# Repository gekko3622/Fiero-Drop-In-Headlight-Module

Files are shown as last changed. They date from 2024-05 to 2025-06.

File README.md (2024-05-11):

# 1987-1988 Pontiac Fiero OEM Drop-In Headlight Motor Controller
**PCB Designed by Ryan Blanchard 4.2024**\
**Based On A Project by WalkerTexan**\
**FOR NON-COMMERCIAL USE ONLY.**



**Important:** Please pay attention to the Bill of Materials (BOM). Some components have been changed from my previous designs.\
**This PCB MUST be fabricated with 2 Oz Outer Copper Weight for power handling and safety.**

## Intro

This is a PCB implementation of WalkerTexan's "Fiero Headlight Controller" project.\
I started this project after getting frustrated with the cost and questionable reliability of used modules.\
While there are new reproductions of the original module available, I found the cost to be too high.

After publishing my original PCB implementation, I was challenged to make it fit inside the original GM module's housing. Here it is.

## Repository Contents

**1. Arduino Program**
- WalkerTexan's code for the Arduino Nano.\
This MUST be programmed onto the Pro Micro for the module to function.

**2. Gerber Files (For Production)**
- These are the files that must be provided to a fabricator to produce a PCB.\
  **VERY IMPORTANT:** This PCB MUST be produced with 2 Oz outer copper weight in order to meet power handling requirements.\
  The provided gerber files will produce an identical copy of the PCB installed in my own car, just minus my logo.

  The Zip file can be directly submitted to a fabricator and contains all of the other individual files in this folder.

**3. KiCad Project Files**
- These are my full design schematic and PCB layout files. Use them for learning PCB design or to create your own custom version of the module.

  This project requires KiCad v8 or higher.

## Requirements
This project requires that you already have a fried 87-88 headlight module. (You're considering this project for a reason, right?)\
A Firebird or Corvette module of similar design can also be used.

- You will need to desolder and re-use the original 4 and 5 pin headers from your original module.
- The original module case will also be reused, but requires a single modification.

## Important Building Tips

**1. Arduino Pro Micro**

Due to the low clearance of the GM module casing, the Pro Micro must be installed lower on its pins than standard.\
It is also installed in a DIP socket to further reduce the mounting height.

My recommendation is to install the DIP socket first, then push the Pro Micro's pins into it.\
While installed, push down the plastic spacer, moving side to side until it's as flush as possible with the socket.



You can really see the difference in this side-by-side:



Once you've adjusted the pins for each side, place the Pro Micro onto the pins and solder it while socketed.

**2. Fuses**

I designed the module to directly solder in standard automotive mini fuses.\
For my own board, I used low profile mini fuses in order to avoid having to trim the fuse legs.

Regular mini fuses will work fine, just trim the legs after soldering.
  - 15 amps should be fine assuming your motors are in good shape.



**3. 4/5 Pin Original Header Pins**

The header pins must be installed slightly pulled out from the board to compensate for the added height of the relays.\
I tried my best to capture an image to demonstrate the needed spacing, but it's hard get a clear shot when assembled.



I found it easiest to install the pins one side at a time, getting them lined up right when installed into the housing.\
The holes for the headers are a pretty tight fit, so you should be able to position them fairly easily without them falling out.\
Once I was satisfied with the fitment, I lightly soldered a pin or two per side while still in the casing just to make sure the alignment was right.

**4. Modifying the Module Case**

The sole casing modification needed is to remove most of the plastic spacers from the back panel.\
The plastic is pretty soft, so I was able to grab and twist with vice grips to remove most of the material.

**You do not need to fully remove the spacers, just enough so the back panel can be re-installed without flexing.**\
**The round corner pieces do not need to be removed.**

Here's a comparison of an intact panel and my hastily trimmed panel. If you have the time, sanding them would give a more precise fit.

image0(2)

## Modifications to Original Source
1. Recreated the schematic diagram in KiCad.
2. Designed a PCB based on the schematic.
3. Added fuses and changed the power-on circuit to draw its power from the second 12V source.
4. Substituted the relays for a smaller part with higher current rating.
5. Adapted for compatibility with the original headlight module.

## Credits
The electrical schematic and Arduino code this project is based on were created by WalkerTexan.\
See his original project here: https://www.hackster.io/walkertexan/fiero-headlight-controller-8eaa4c

KiCad Schematic and PCB Layout/Design by Ryan Blanchard.

## License
This project is published under the Creative Commons Attribution-NonCommercial-ShareAlike 4.0 International license.\
Use of this project for commercial purposes is prohibited.

For full details, see the license file.

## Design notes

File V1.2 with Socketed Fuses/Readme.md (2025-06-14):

V1.2 maintains the same BOM but adds socketed fuse holders.\
The specific holders I used are the micro fuse holders on this listing:\
https://www.aliexpress.us/item/2255800354773238.html

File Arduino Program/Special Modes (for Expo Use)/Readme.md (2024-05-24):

# Custom Arduino Program To Enable Special Toggles
**Legal Disclaimer: This program is FOR OFF-ROAD AND EXHIBITION USE ONLY. Winking and sleepy headlight mode are probably not legal on most public roads.**

*Personal disclaimer: I am not a programmer by trade nor am I a particularly good one. Use my modifications at your own risk.*

## How to Use
Program the file "Fiero Headlight Toggle Modes 1_0.ino" to your Arduino in place of the standard programming. It contains most of the same code as the original but with additions to enable fun headlight behaviors.

Modes are activated using the headlight switch. Upon turning the headlight switch off, you have 1 second to enter a command (detailed below).

If the headlight switch is left off for more than 1 second, the headlights will close and the module will turn off.

## Available Toggles
### Wink
You can wink either the left or right headlight by turning the headlight switch off, then back on within 1 second.\
The amount of time between turning the switch off and on determines which side will wink.

**Right headlight:** turn the headlight switch off and on within half a second.

**Left headlight:** turn the headlight switch off, wait half a second, then turn it back on.

### Sleepy Mode
Sleepy mode and normal mode are toggled back and forth using the same command.\
To switch between normal and sleepy mode, turn the headlight switch off and on twice. (off>on>off>on)

Each flip must be completed within one second of the last action.

Winking in sleepy mode works the same as normal.

## Troubleshooting
**Sleepy mode winks are not returning the lights to the correct height.**
  * You will need to adjust the motor run timing manually for your own car.
    * For the left light, adjust the value of 'count' on line 385.
    * For the right light, adjust the value of 'count' on line 489.
  * Setting 'count' to a higher value will reduce the motor run time, lifting the light lower.
  * Setting 'count' to a lower value will increase the motor run time, lifting the light higher.
  * 'count' has a maximum limit of 150. Setting it to 150 or higher will not run the motor at all.

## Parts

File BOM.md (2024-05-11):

# Bill of Materials

**Note:** The Quantity column indicates the number of each component that is required.\
Many electrical components are sold in bulk. Please pay attention to each product page so you don't massively overpurchase.

| Component | Quantity | Position | Link | Notes |
| --- | --- | --- | --- | --- |
| Arduino Pro Micro | 1 | A1 | https://www.amazon.com/dp/B01MTU9GOB/ | Program the board as "Arduino Leonardo" |
| 30A Current Sensor Module | 2 | U2, U3 | https://www.amazon.com/dp/B07SPRL8DL/ | Terminals and pins must be desoldered |
| JQC-T78-DC05V-C | 4 | K1, K2, K3, K4 | https://www.amazon.com/dp/B07JHC6LYR/ | |
| JQC-T78-DC12V-C | 1 | K5 | https://www.amazon.com/dp/B07JGSJXF1/ | |
| 1N4001 Rectifier Diode | 5 | CR1, CR2, CR3, CR4, CR5 | https://www.amazon.com/gp/product/B07Q3HBM63/ | |
| 2N2222A Transistor | 8 | Q1, Q2, Q3, Q4, Q5, Q6, Q7, Q8 | https://www.amazon.com/CHANZON-BJT-Transistors-2N2222A-TO-92-100/dp/B083TNXLHD/ | |
| 1K 0.25w Resistor | 7 | R2, R4, R5, R6, R7, R8, R9 | https://www.amazon.com/dp/B07HDDWFDD/ | |
| 10K 0.25w Resistor | 3 | R1, R3, R10 | https://www.amazon.com/dp/B0B4JFPHTW/ | |
| 10UF 25V Capacitor | 2 | C1, C2 | https://www.amazon.com/dp/B07YBCF9NG | |
| L7805CV Voltage Regulator | 1 | U1 | https://www.amazon.com/dp/B083TBMJJS | |
| DIP Socket | 1 | A1 | https://www.amazon.com/dp/B07H3ST9SL | Used to socket the Pro Micro |
| 15 Amp Mini/LP-Mini Fuse  | 2 | F1, F2 | https://www.amazon.com/dp/B0CHZ7NQ3Y or https://www.amazon.com/dp/B0CHZ8QFMV/ | Pick whichever type you prefer |
| 2.54mm Breakaway Pins | 1 package | U2, U3 | https://www.amazon.com/dp/B07PKKY8BX/ | Use to mount the current sensors. Cut to 3-pin lengths and remove the middle pin for the 2-pin side |

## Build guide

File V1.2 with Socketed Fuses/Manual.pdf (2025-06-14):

# 87-88 Fiero Headlight Module

V1.2 by Ryan Blanchard

Based on an original schematic and code by WalkerTexan

# Basic Assembly Guide

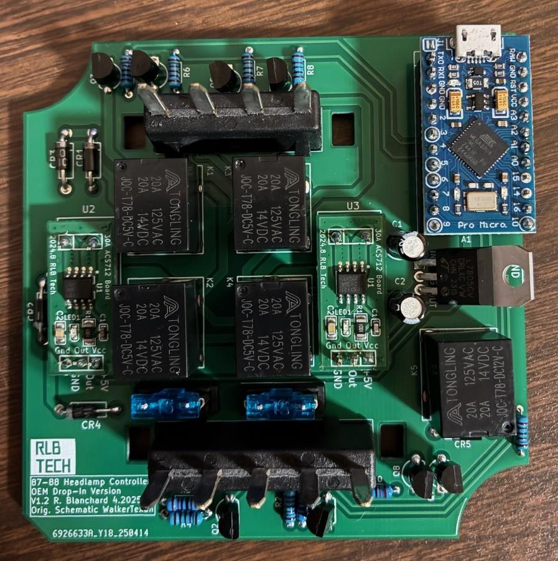
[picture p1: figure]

# DISCLAIMER

Before proceeding, please read and understand the following:
1. This is a DIY project designed by hobbyists.
2. The kit is provided with no warranty expressed or implied.
3. Although I have operated this module in my own car for one year with no problems, I am still only one man with one car.
4. You are installing this headlight motor control module into your car at your own risk. As with all electronic devices, improper assembly or handling can risk electrical shock or fire.
5. By assembling and using this DIY kit, you agree to hold harmless Ryan Blanchard and WalkerTexan in the event of any and all malfunction or damages caused by its use.

# Kit Contents

Each kit contains:

1x Printed Circuit Board | 7x 1K ohm 0.25 watt resistors
1x Pro Micro microcontroller board | 3x 10K ohm 0.25 watt resistors
4x JQC-T78-DC05V-C 5 volt relays | 2x 10 uF 25V Capacitors
1x JQC-T78-DC12V-C 12 volt relays | 1x L7805CV voltage regulator
5x 1N4001 rectifier diodes | 1x 24-pin DIP socket
8x 2N2222A transistors | 2x low-profile fuse holders
2x 30A current sensor modules | 2x low-profile 15A fuses
2x 2-pin headers for current sensor | 2x plastic spacers for vehicle harness pins

2x 3-pin headers for current sensor

You will need to provide:

- Soldering/desoldering supplies
- 4-pin and 5-pin headers from an original Fiero/Firebird/Corvette headlight module
- Original casing from an original Fiero/Firebird/Corvette headlight module

# Assembly

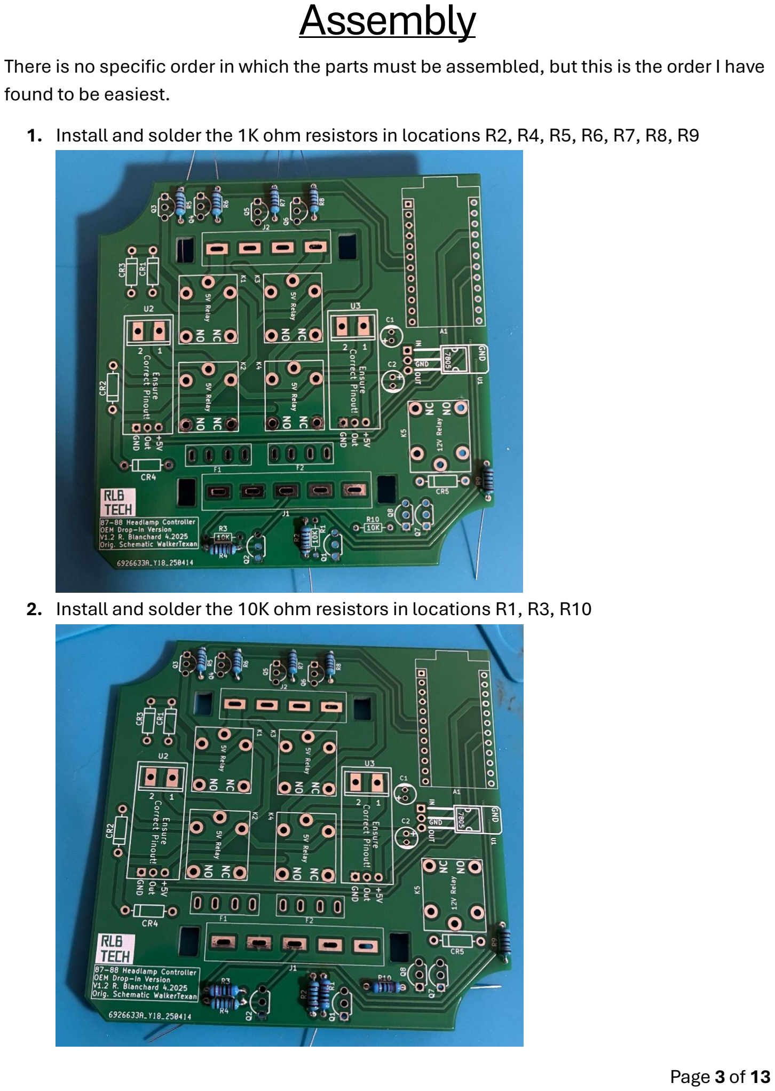
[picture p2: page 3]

There is no specific order in which the parts must be assembled, but this is the order I have found to be easiest.

### 1. Install and solder the 1K ohm resistors in locations R2, R4, R5, R6, R7, R8, R9

### 2. Install and solder the 10K ohm resistors in locations R1, R3, R10

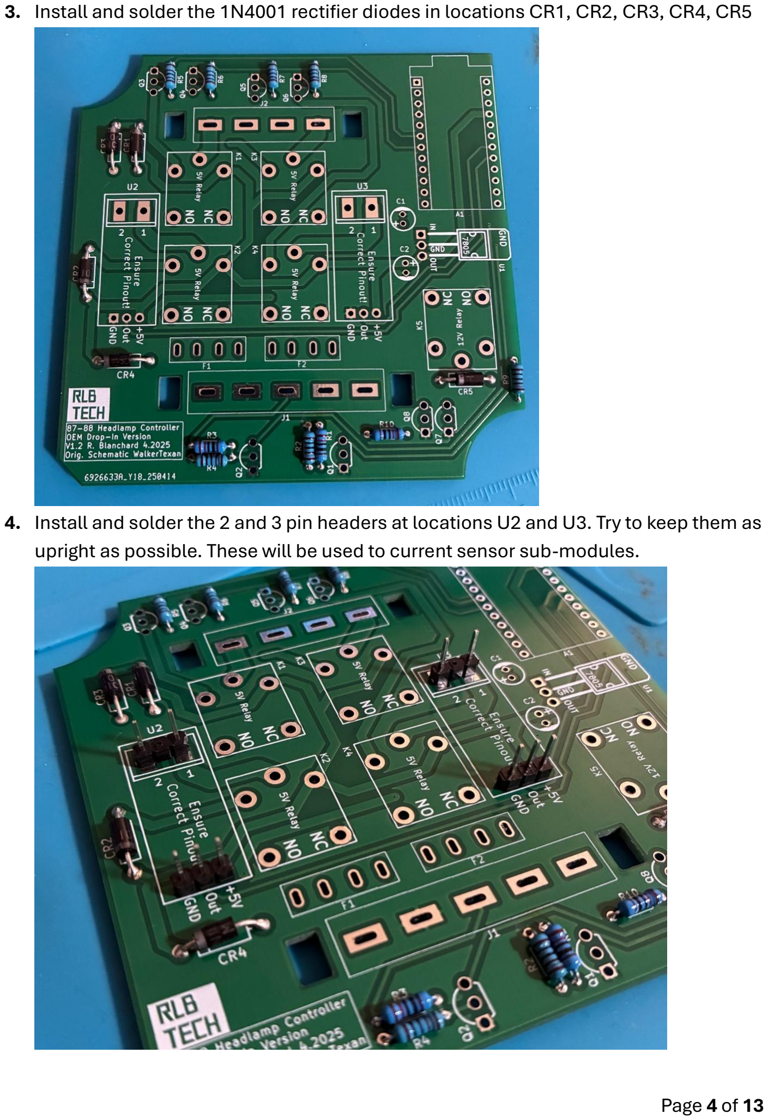
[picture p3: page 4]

### 3. Install and solder the 1N4001 rectifier diodes in locations CR1, CR2, CR3, CR4, CR5

### 4. Install and solder the 2 and 3 pin headers at locations U2 and U3. Try to keep them as

upright as possible. These will be used to current sensor sub-modules.

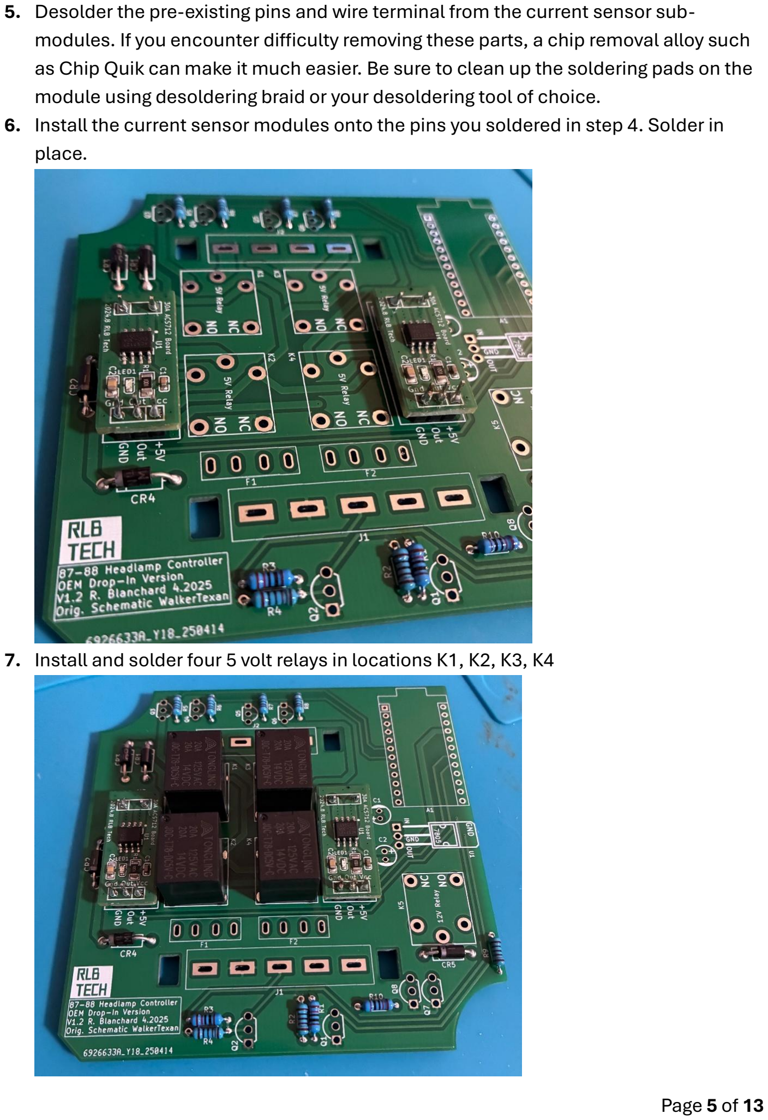
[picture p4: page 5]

### 5. Desolder the pre-existing pins and wire terminal from the current sensor sub-

modules. If you encounter difficulty removing these parts, a chip removal alloy such as Chip Quik can make it much easier. Be sure to clean up the soldering pads on the module using desoldering braid or your desoldering tool of choice.

### 6. Install the current sensor modules onto the pins you soldered in step 4. Solder in

place.

### 7. Install and solder four 5 volt relays in locations K1, K2, K3, K4

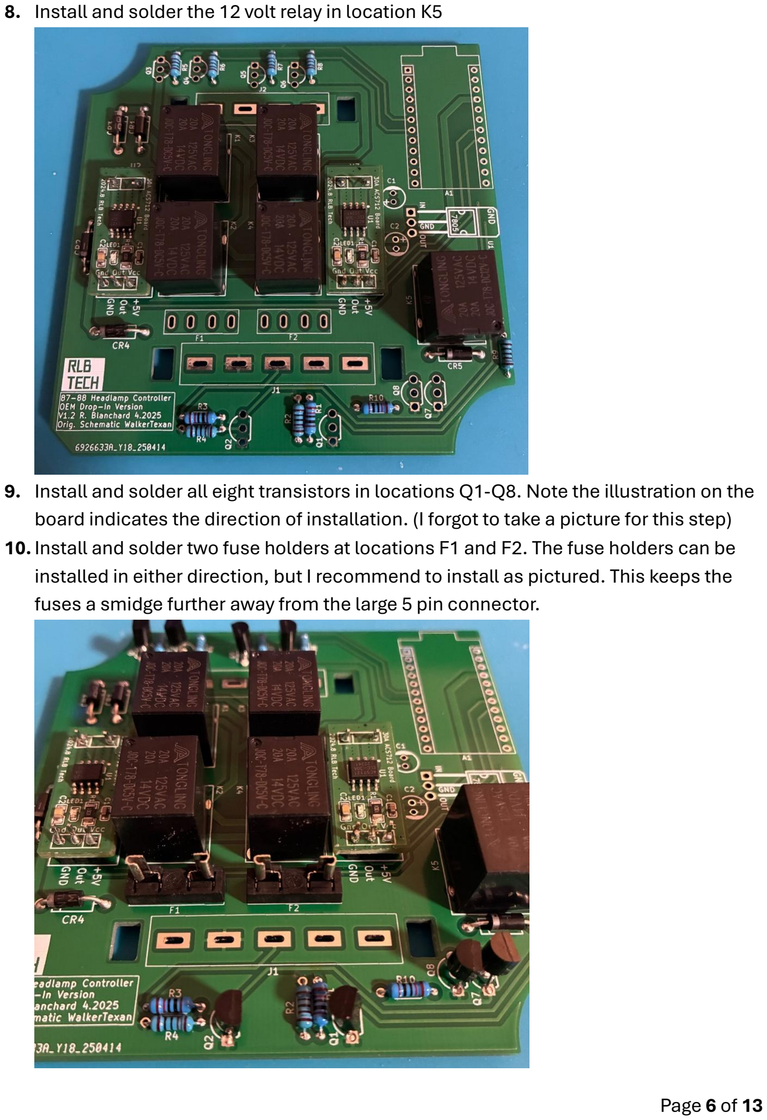
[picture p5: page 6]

### 8. Install and solder the 12 volt relay in location K5

9. Install and solder all eight transistors in locations Q1-Q8. Note the illustration on the board indicates the direction of installation. (I forgot to take a picture for this step) 10.Install and solder two fuse holders at locations F1 and F2. The fuse holders can be installed in either direction, but I recommend to install as pictured. This keeps the fuses a smidge further away from the large 5 pin connector.

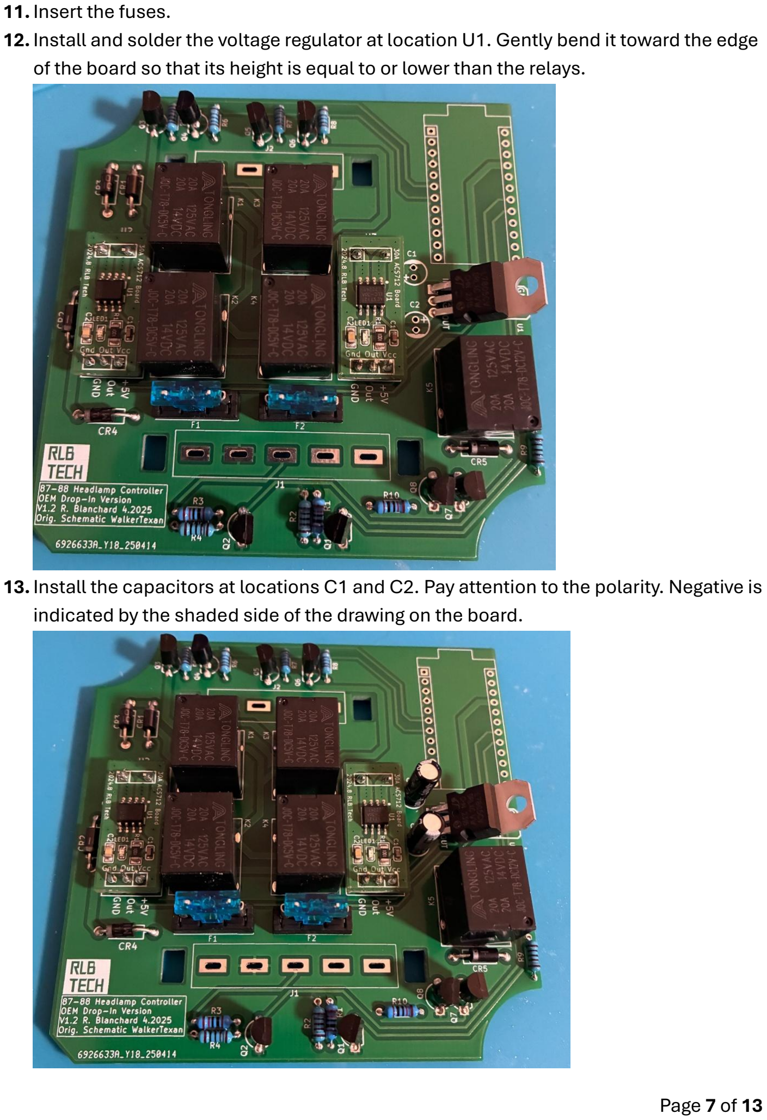
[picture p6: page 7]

11.Insert the fuses.
12.Install and solder the voltage regulator at location U1. Gently bend it toward the edge of the board so that its height is equal to or lower than the relays.

13.Install the capacitors at locations C1 and C2. Pay attention to the polarity. Negative is indicated by the shaded side of the drawing on the board.

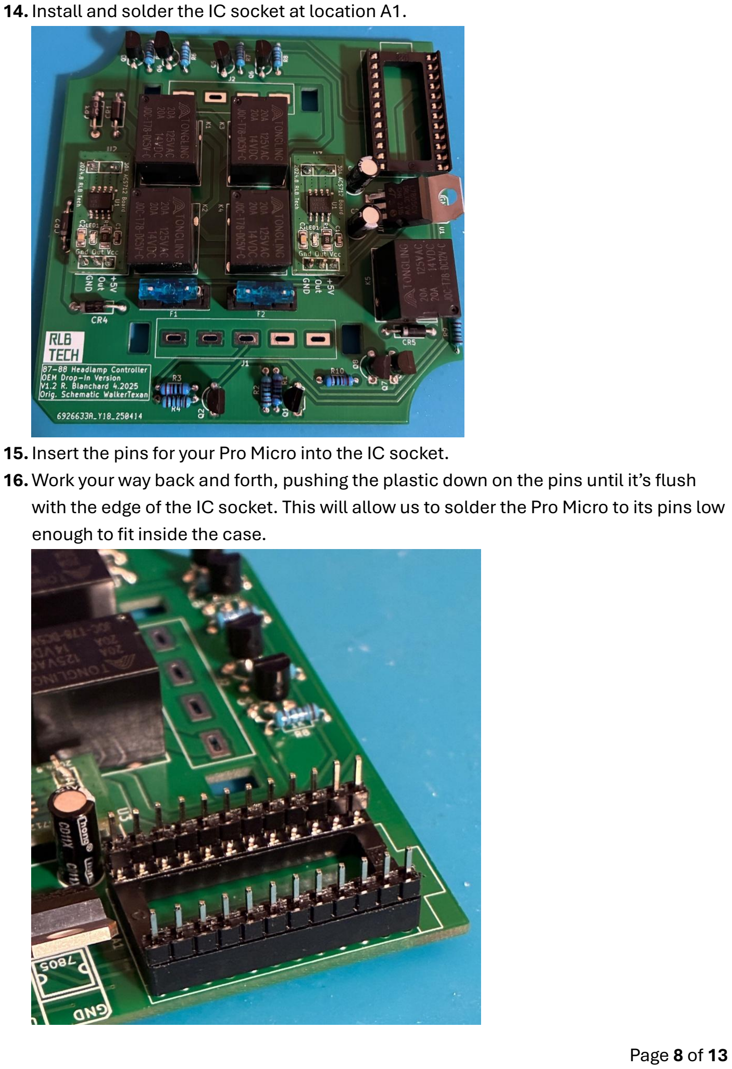
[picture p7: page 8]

14.Install and solder the IC socket at location A1.

15.Insert the pins for your Pro Micro into the IC socket.
16.Work your way back and forth, pushing the plastic down on the pins until it’s flush with the edge of the IC socket. This will allow us to solder the Pro Micro to its pins low enough to fit inside the case.

17.Place the Pro Micro board onto the pins and solder all pins.

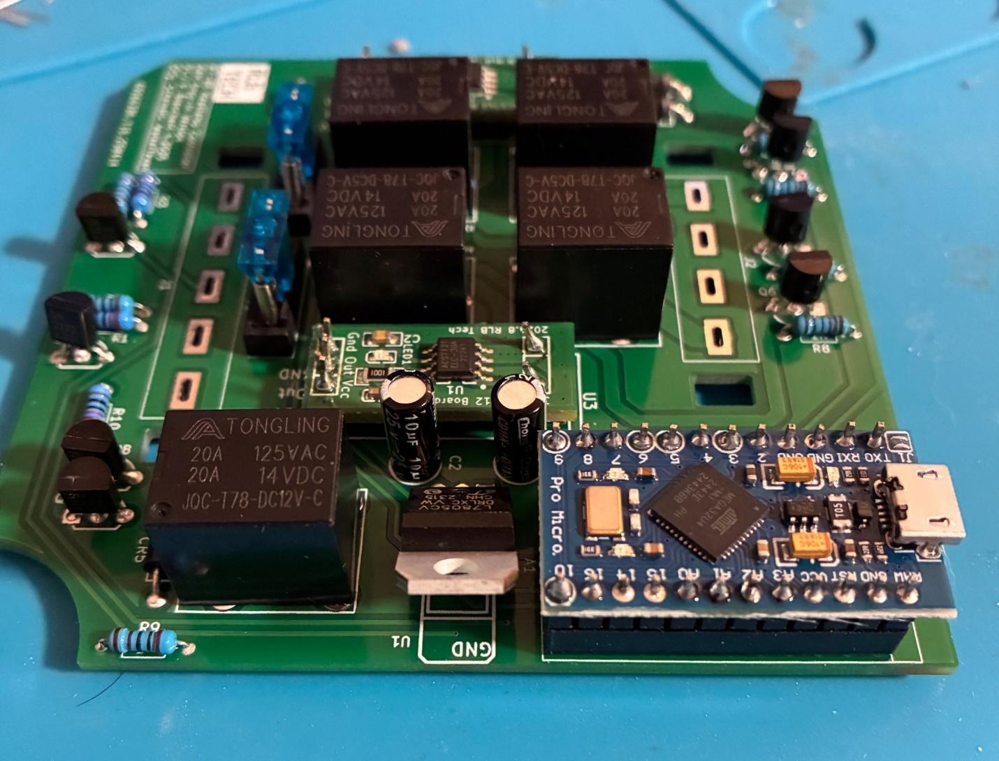
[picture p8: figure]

18.Prepare your 4 and 5-pin headers that were removed from your original GM module. Install the 1.5 mm plastic spacers onto the solder side of the pins, then insert them into the board.
19.With both headers inserted, gently place the board into the original top module casing to properly align the pins.

If the pins are too loose in the board and fall out, apply a very small amount of solder to a single center pin to tack it in place. You can then apply heat with your soldering iron to make adjustments and check fitment with the top case.
20.Once you are satisfied with the alignment of the pins, solder the header pins into place.
21.Assembly is now complete. Proceed to the next section: Programming the Pro Micro

# Programming the Pro Micro

If you do not already have it, you will need to download the Arduino IDE program from: https://www.arduino.cc/en/software/
1. Launch the Arduino IDE
2. Open the Tools menu -> Board -> Arduino AVR Boards
3. Select Arduino Leonardo

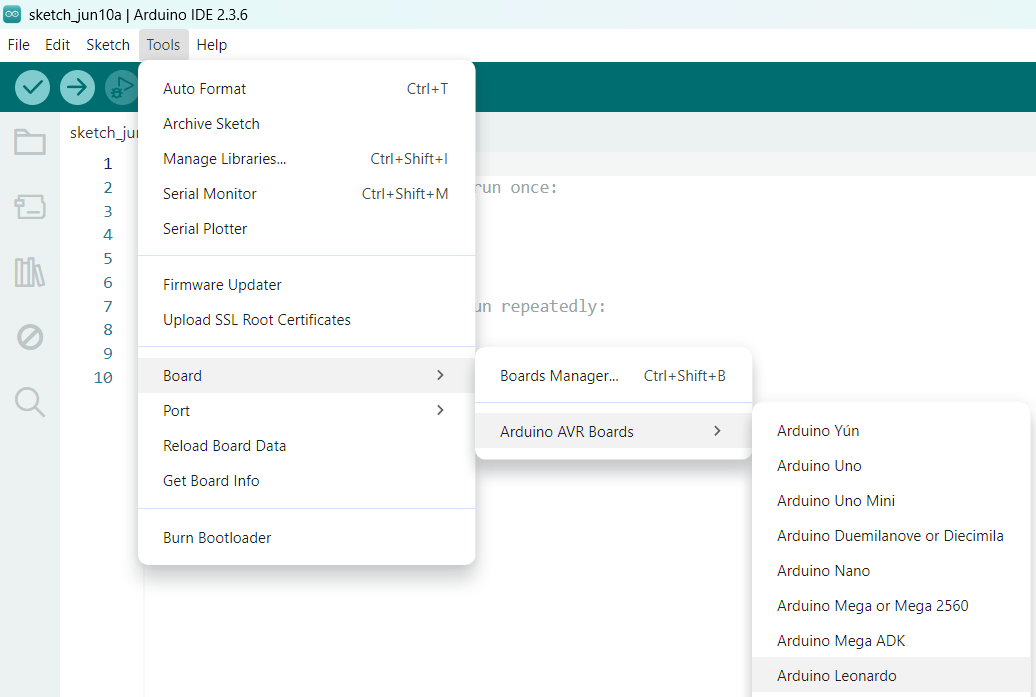
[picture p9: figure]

4. Connect the Pro Micro to your computer with an appropriate USB cable.
5. Open the Tools menu again and this time select Port.

6. Select the port with (Arduino Leonardo) next to it.

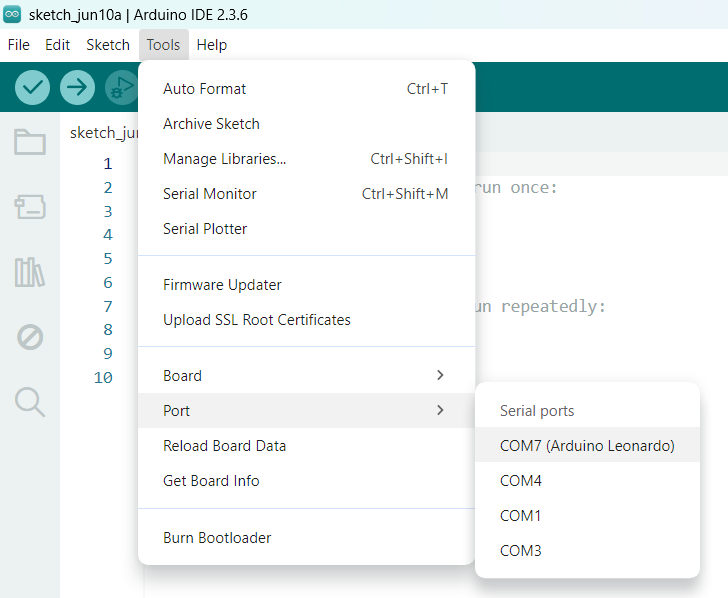
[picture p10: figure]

7. Next we need to get to program code that we want to write to the Pro Micro.
8. Visit my Github page at https://github.com/gekko3622/Fiero-Drop-In-Headlight-Module (https://github.com/gekko3622/Fiero-Drop-In-Headlight-Module)
9. Next open the “Arduino Program” folder
10. Open the file: fiero_headlight_door_cont_v2_power_relay_ino.pde then either copy the full text of the code or download the file.

11. Open fiero_headlight_door_cont_v2_power_relay_ino.pde in the Arduino IDE OR paste the copied code into the IDE, making sure to erase any pre-existing code before pasting.
12. Open the Sketch menu and click Upload. The IDE will the compile the code and upload it to the Pro Micro.

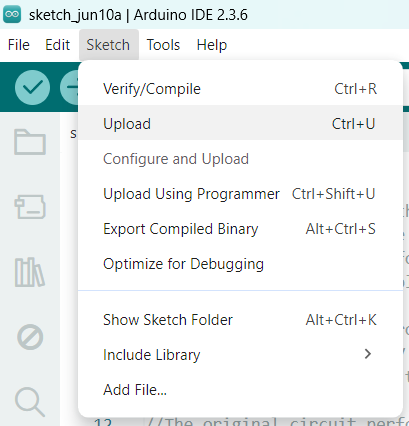
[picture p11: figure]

13. You should receive a message in the bottom status window indicating success. If you receive an error, first be sure that you copied the code in its entirety with no additional text.
You may see a red message that appears to be an error, but as long as the “Upload completed” message pops up, it should have been successful.
14. You can test that programming was successful by plugging the Pro Micro into the module and plugging it into your USB cable. You should almost immediately hear two relays click then shortly after they will click a second time. This is the module running its start-up process, opening the headlights.

# Putting It All Together

You’re in the home strech, all that’s left is to modify the module case back to fit. Sand down or break off the four center supports on the case back as shown below:

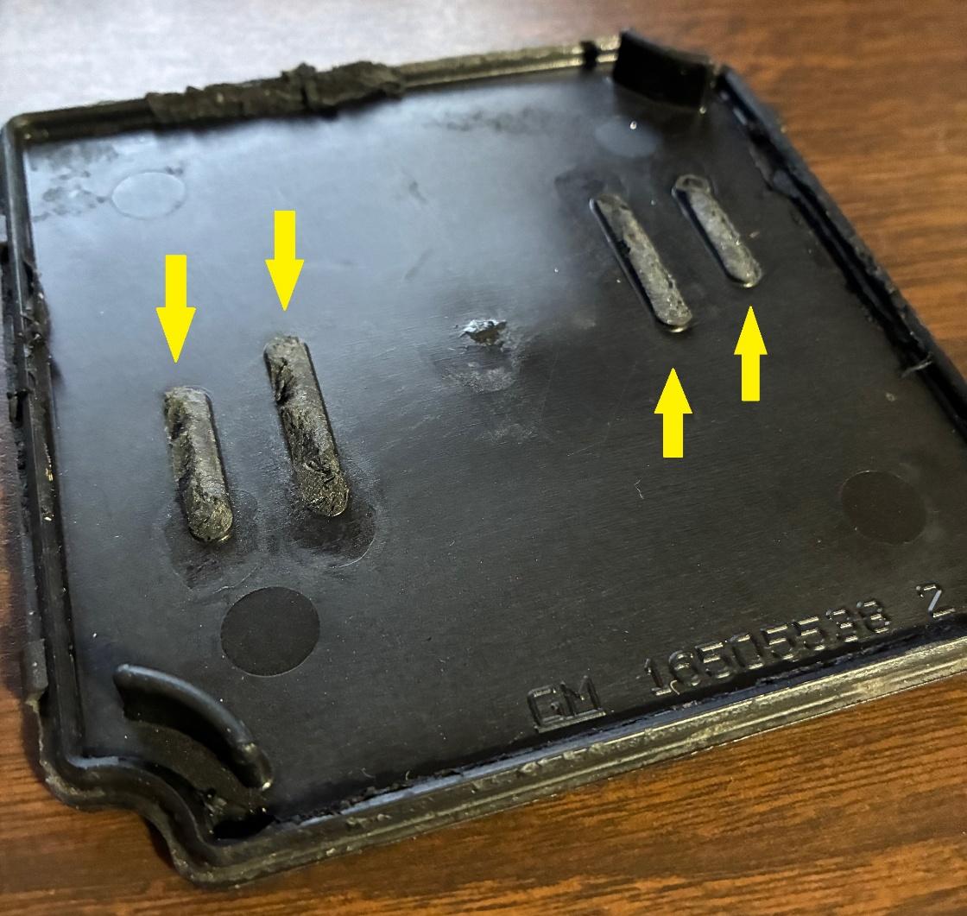
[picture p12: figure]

1. Place the finished module into the case and snap the back panel on.
2. Install into car and test.

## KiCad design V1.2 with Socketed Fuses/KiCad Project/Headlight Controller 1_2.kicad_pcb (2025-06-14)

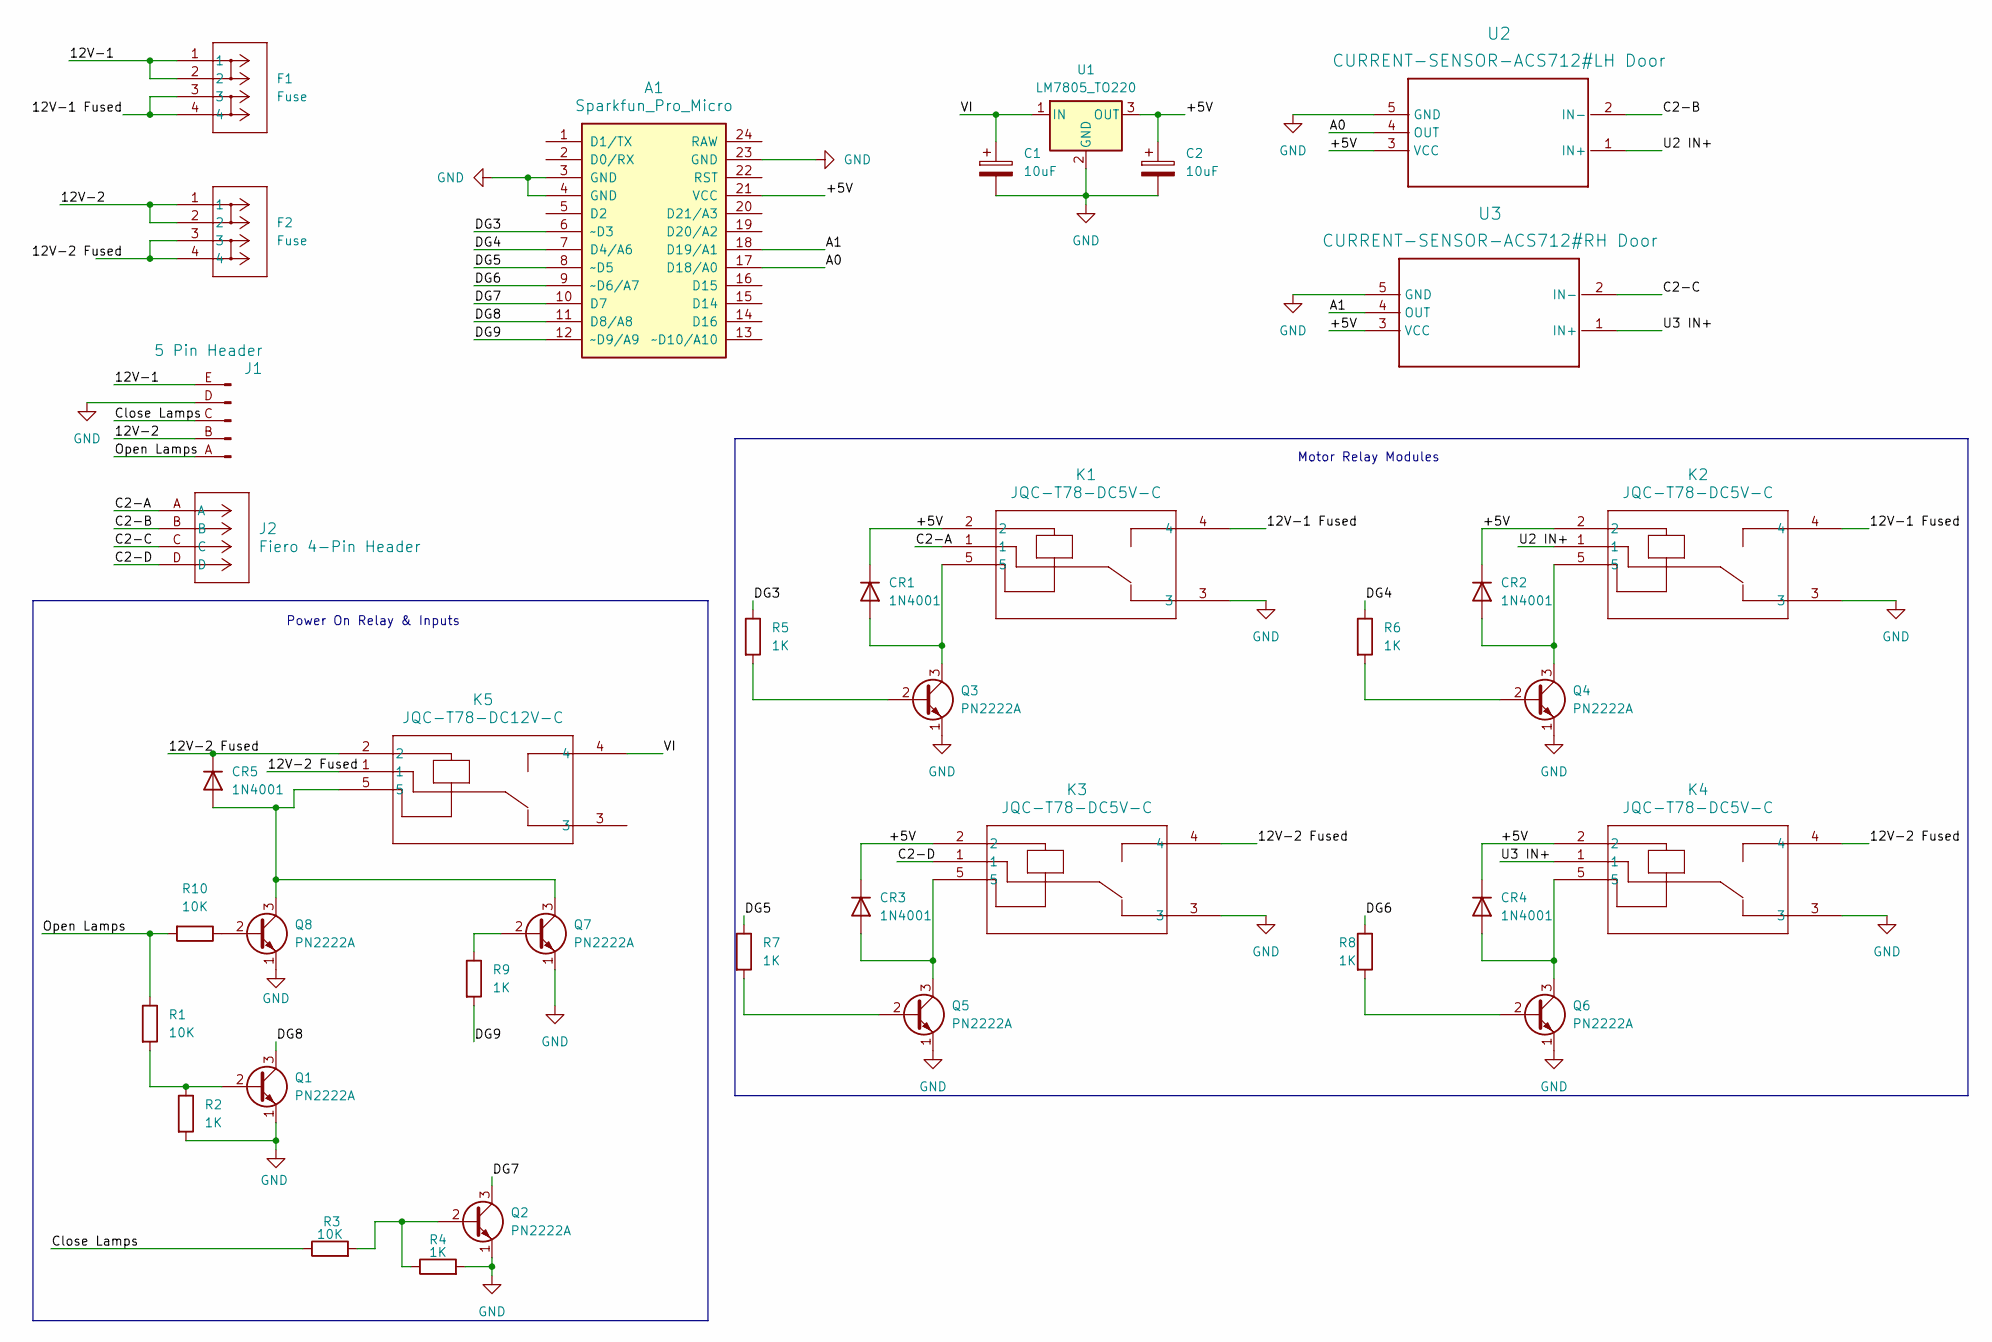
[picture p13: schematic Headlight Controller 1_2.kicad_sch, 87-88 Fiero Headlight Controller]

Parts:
A1: Sparkfun_Pro_Micro
C1, C2: 10uF; CAP-TH_BD5.0-P2.00-D0.8-FD
CR1, CR2, CR3, CR4, CR5: 1N4001; DIODE-1N4001
F1, F2: Fuse; LP-Mini Fuse Holder
J1: 5 Pin Header; Fiero Headlight Controller 5-Pin
J2: Fiero 4-Pin Header; Fiero Headlight Controller 4-Pin
K1, K2, K3, K4: JQC-T78-DC5V-C
K5: JQC-T78-DC12V-C; JQC-T78-DC5V-C
Q1, Q2, Q3, Q4, Q5, Q6, Q7, Q8: PN2222A; 2N2222A
R1, R3, R10: 10K; R_Axial_DIN0204_L3.6mm_D1.6mm_P7.62mm_Horizontal
R2, R4, R5, R6, R7, R8, R9: 1K; R_Axial_DIN0204_L3.6mm_D1.6mm_P7.62mm_Horizontal
U1: LM7805_TO220; L7805
U2: CURRENT-SENSOR-ACS712#LH Door; ACS712_A
U3: CURRENT-SENSOR-ACS712#RH Door; ACS712_A

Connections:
/12V-1: F1.1, F1.2, J1.E
/12V-1 Fused: F1.3, F1.4, K1.4, K2.4
/12V-2: F2.1, F2.2, J1.B
/12V-2 Fused: CR5.C (K), F2.3, F2.4, K3.4, K4.4, K5.1, K5.2
/+5V: A1.21 (VCC), C2.1, CR1.C (K), CR2.C (K), CR3.C (K), CR4.C (K), K1.2, K2.2, K3.2, K4.2, U1.3 (OUT), U2.3 (VCC), U3.3 (VCC)
/A0: A1.17 (D18/A0), U2.4 (OUT)
/A1: A1.18 (D19/A1), U3.4 (OUT)
/C2-A: J2.A, K1.1
/C2-B: J2.B, U2.2 (IN-)
/C2-C: J2.C, U3.2 (IN-)
/C2-D: J2.D, K3.1
/Close Lamps: J1.C, R3.1
/DG3: A1.6 (~D3), R5.1
/DG4: A1.7 (D4/A6), R6.1
/DG5: A1.8 (~D5), R7.1
/DG6: A1.9 (~D6/A7), R8.1
/DG7: A1.10 (D7), Q2.3 (C)
/DG8: A1.11 (D8/A8), Q1.3 (C)
/DG9: A1.12 (~D9/A9), R9.2
/Open Lamps: J1.A, R1.1, R10.2
/U2 IN+: K2.1, U2.1 (IN+)
/U3 IN+: K4.1, U3.1 (IN+)
/VI: C1.1, K5.4, U1.1 (IN)
GND: A1.3 (GND), A1.4 (GND), A1.23 (GND), C1.2, C2.2, J1.D, K1.3, K2.3, K3.3, K4.3, Q1.1 (E), Q2.1 (E), Q3.1 (E), Q4.1 (E), Q5.1 (E), Q6.1 (E), Q7.1 (E), Q8.1 (E), R2.2, R4.2, U1.2 (GND), U2.5 (GND), U3.5 (GND)
unnamed: Q1.2 (B), R1.2, R2.1
unnamed: Q2.2 (B), R3.2, R4.1
unnamed: Q3.2 (B), R5.2
unnamed: CR1.A, K1.5, Q3.3 (C)
unnamed: Q4.2 (B), R6.2
unnamed: CR2.A, K2.5, Q4.3 (C)
unnamed: Q5.2 (B), R7.2
unnamed: CR3.A, K3.5, Q5.3 (C)
unnamed: Q6.2 (B), R8.2
unnamed: CR4.A, K4.5, Q6.3 (C)
unnamed: Q7.2 (B), R9.1
unnamed: CR5.A, K5.5, Q7.3 (C), Q8.3 (C)
unnamed: Q8.2 (B), R10.1

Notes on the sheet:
Motor Relay Modules
Power On Relay & Inputs

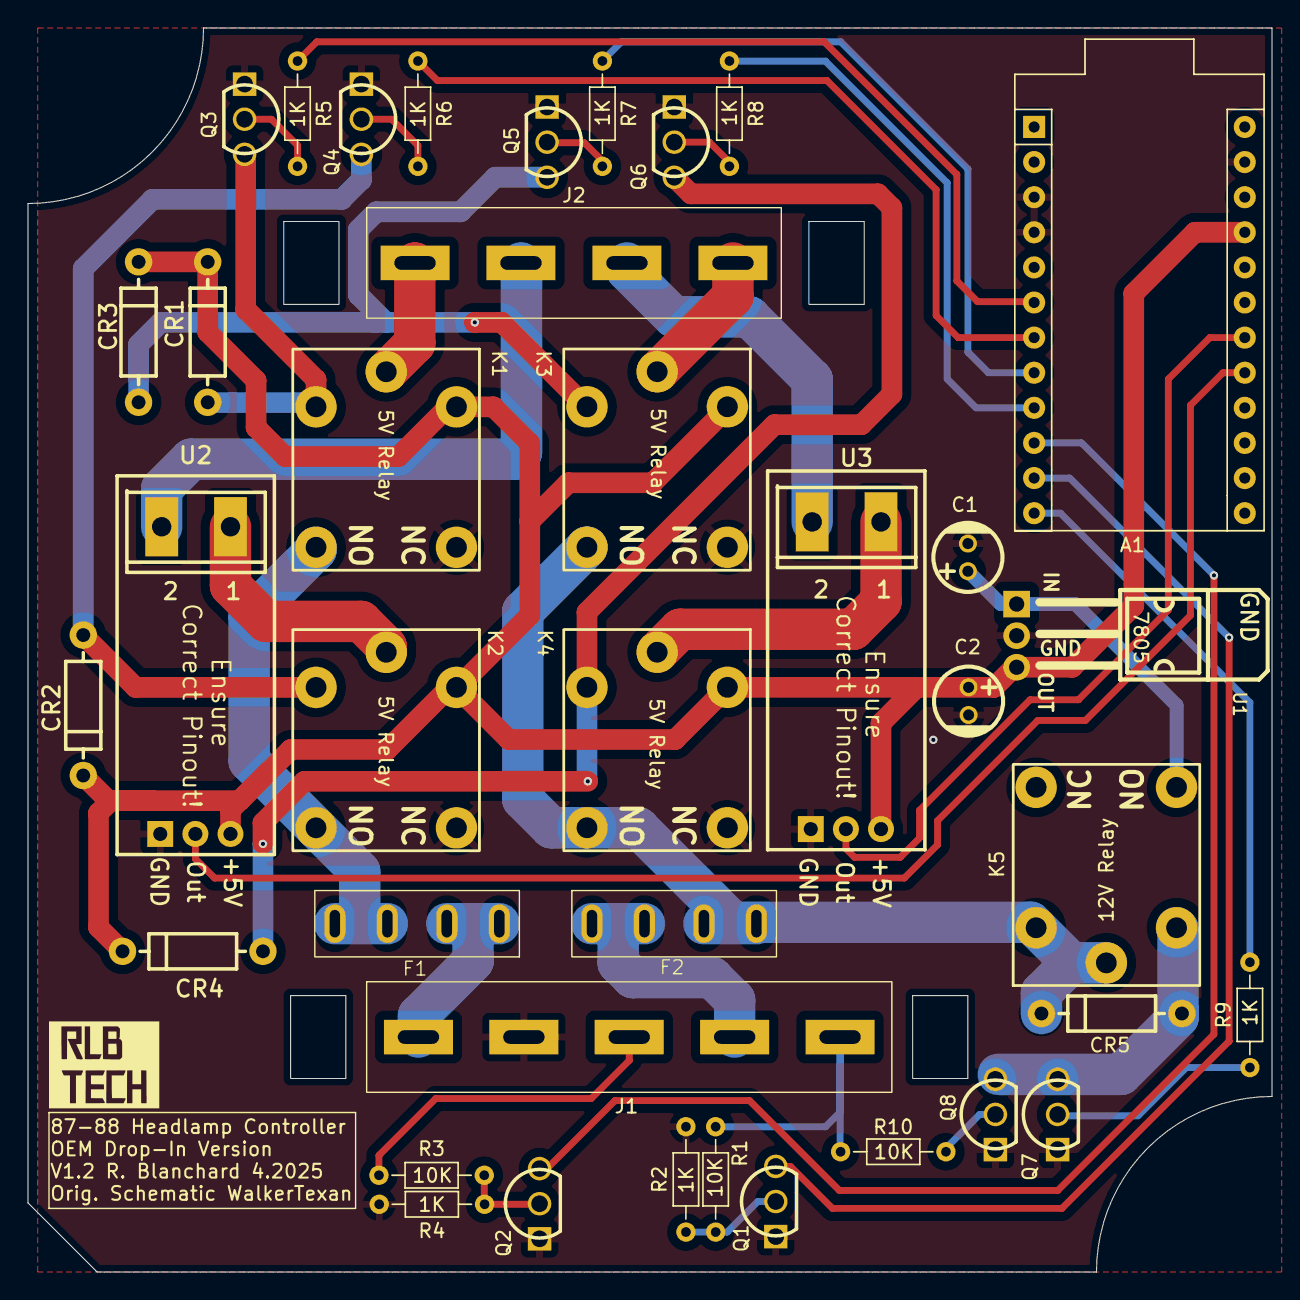
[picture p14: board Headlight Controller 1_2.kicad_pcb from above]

Board: 2 copper layers, 90.0 x 90.0 mm, 38 parts (0 on the bottom side), 37 nets.

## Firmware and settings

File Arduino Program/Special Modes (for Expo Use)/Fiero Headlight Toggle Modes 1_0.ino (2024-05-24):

//POWER RELAY version
//This program along with the circuitry replaces the Fiero Headlight Door Module with
//a modern equivalent.  The module in my car is dead so this has become a necessity.
//NOTE THAT THIS is a fix for 87 and 88 modules and NOT the prior design although
//it may be reasonably simple to implement for those if necessary.

//The Fiero Light switch produces two signals: one is at 12V when the lights are off
//while the other is at 12V when the lights are on.  Both are floating and essentially
//at ground potential when the parking lights are on.

//The original circuit performed a crude H bridge using a 4PDT relay which is an
//expensive component and hard to find in a format that fits the original module.  This
//approach uses four SPDT relays in an Arduino-compatible module to form the H bridge.
//The relay module is designed as active-low on the input signals.

//The original circuit used programmable logic to sense the current draw of each motor.
//If the motor stalled at either the ends or during travel then a high current would
//occur and the logic would remove power from the offending motor.  The relay in the
//circuit was limited to 5A so it is assumed that the maximum allowable continuous
//current was less than this.  Bad assumption.  GM did a poor design because the current
//is closer to 12A inrush as measured with an ammeter, although for short duration.  This explains
//the failed relays over the years and possibly causes the failures of the FETs.
//This approach uses two hall-effect Arduino-compatible current sensors to detect
//this condition so that power is removed quickly.

//The original circuit also provided a timer of approximately 2.5 seconds for the
//motors to reach either open or closed position.  This approach will do this as well.

//Program written by Michael Walker Copyright 03/2021.  Program is free for use without
//any warranty either expressed or implied.

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
int LH_zero_current, RH_zero_current; //values read to "calibrate" the current sensors
int Current_limit;
int count, Loop_count;
int Toggle_count, Toggle_loop_count;
int Second_toggle_count, Second_toggle_loop_count;
int Sleepy_count, Sleepy_loop_count;
int current_value;
bool Do_wink_left;
bool Do_wink_right;
bool Mode_sleepy;
bool Mode_normal;
bool Second_toggle;
void Open_doors();//routine opens the doors and checks for damaging current
void Close_doors();//routine closes the doors and checks for damaging current
void Check_toggles();//checks for mode toggle before closing the headlights
void Wink_left();//Winks the left headlight
void Wink_right();//Winks the right headlight
void Sleepy_mode();//Lowers headlights halfway


void setup()
{
  // pinitialization will occur when power is applied to the circuit through the 12V relay, i.e. when the
  //headlight switch is ON.  The lighting circuits have live power through that relay only.
  //TURN ON THE RELAY DRIVER IMMEDIATELY TO KEEP POWER ON THE CIRCUIT!  This driver allows the circuit
  //to remain ON when the switch is turned OFF long enough to retract the lights.
  //The circuit remains LIVE as long as the lights are ON once this is initiated; you must turn OFF the 
  //headlights in order to remove power from the circuit.

    pinMode(9, OUTPUT);//driver control for the 12V relay to power the module
    digitalWrite(9, HIGH);//keep the power ON until the doors are closed.
    
  //Keep this is mind when servicing any of the headlight components because they
  //can actuate at any time if the headlight switch is ON!
//  Serial.begin(9600);//debug and will probably be removed later.
//  Serial.println("Fiero Headlight Door Module V2 is Alive and Well!");

  //Current sensor ACS712/30A centers at 2.5V at zero current when operating with a 5V supply.  The
  //output is proportional to the current with 66mV equivalent to 1A.  The Arduino Nano A/D is 10-bit
  //so each count is 5/1024 or 4.88mV (14 counts per amp).  At zero current the value should be approximately 512.  A 5A
  //value should be approximately 5 * 66mV or 330mv.  That corresponds to a count of 330mV/4.88mV
  //which is approximately 68 counts above the zero current value. A value of 27 would be approximately
  //2A and 41 would be 3A.  Experimentation shows that the inrush current of the motor is approximately 
  //8A and sometimes triggers an overcurrent up to about 11A.  This means that the overcurrent level 
  //needs to be at least 12A and possibly more to account for ambient temperature.  A value of 14.8A
  //seems to give perfect results without overcurrent occurring and is low enough to prevent burnout of
  //the motor or the fuse links while accounting for higher current during cold conditions.
  //Increasing the delay time at initial startup to account for inrush might be a better approach since the
  //current limit could be lowered to a value closer to 8A and may be implemented in the future if it seems
  //prudent.
  Current_limit = 200; //approximately 14.8A above the "zero current" value to account for inrush current
  Loop_count = 150;  //number of loops with 10ms delay to equal 2.5 seconds. Accounting for A/D reads
                    //and logic every 10ms makes this number less than expected 250. Matches original system.
  Toggle_loop_count = 100; //Gives approximately 1 second of time to toggle the headlight switch to engage special modes
  Second_toggle_loop_count = 100; //Gives 1 second of time to toggle the switch off a second time
  Sleepy_loop_count = 100; ////Gives 1 second of time to toggle the switch on a second time to engage sleepy mode
  Mode_sleepy = false;
  Mode_normal = true;
  Second_toggle = false;
  Do_wink_left = false;
  Do_wink_right = false;
  //define the DIO pins
  pinMode(3, OUTPUT);//LH OPEN drive
  pinMode(4, OUTPUT);//LH CLOSE drive
  pinMode(5, OUTPUT);//RH OPEN drive
  pinMode(6, OUTPUT);//RH CLOSE drive
  pinMode(7, INPUT_PULLUP);//C1-C white wire CLOSE headlight switch signal
  pinMode(8, INPUT_PULLUP);//C1-A yellow wire OPEN headlight switch signal

  digitalWrite(3, LOW);   // turn off LH OPEN drive
  digitalWrite(4, LOW);   // turn off LH CLOSE drive
  digitalWrite(5, LOW);   // turn off RH OPEN drive
  digitalWrite(6, LOW);   // turn off RH CLOSE drive
 
  //Power has been applied so headlights were commanded. Open the doors.
  Open_doors();
  
}//end of setup

void loop()
{


  //The loop will check the condition of the two Headlight switch signals every
  //100ms.  The signals are active LOW to the circuit.

  //If DG7 is low and DG8 is high then the light switch is off so the doors are ordered CLOSED.
  if (digitalRead(7) == LOW && digitalRead(8) == HIGH)
  {
//       Serial.println("Light Switch is OFF ");//debug
    Check_toggles();
  }

  delay(100);//wait 100ms before checking again
}// end of loop

void Open_doors()
{
  //This routine commands the LH and RH doors to OPEN and allows 2.5 seconds for
  //that to happen.  The current is monitored every 10ms and if it exceeds the
  //base zero current value plus/minus the high limit value then power is immediately
  //removed from the OPEN relay for the bad door.
  //The relays are turned off after the 2.5 seconds has
  //transpired unless turned off sooner due to overcurrent.

  //If the overcurrent only happens on one door then that door will likely be left
  //in a partially open state.  This allows you to detect which door was the problem
  //in case it isn't obvious for other reasons, like bad noises.  If nothing else
  //it allows you to crank the light to the proper position while the other remains
  //usable.

  Serial.println("Open Doors now");
    
  //no current should be present through the motors at this point so find the quiescent
  //value from the sensors
  LH_zero_current = analogRead(0); //this should be approximately 512 counts
  RH_zero_current = analogRead(1); //this should be approximately 512 counts
  Serial.print("Zero Current LH=");
  Serial.println(LH_zero_current);
  Serial.print("Zero Current RH=");
  Serial.println(RH_zero_current);
  count = 0;
  //Make sure CLOSE signals are OFF
  digitalWrite(4, LOW); //close is off for LH
  digitalWrite(6, LOW); //close is off for RH
  //now turn ON OPEN signals
  digitalWrite(3, HIGH);//LH is on
  digitalWrite(5, HIGH);//RH is on

  while (count < Loop_count) //wait for doors to complete operation or overcurrent happens
  {
    current_value = analogRead(0);//LH current reading
    //overcurrent? shut LH down
    if (current_value > (LH_zero_current + Current_limit)) 
    {
      Serial.print("Overcurrent LH=");
      Serial.println(current_value);  
      digitalWrite(3, LOW);
    }
    if (current_value < (LH_zero_current - Current_limit))
    {
      Serial.print("Overcurrent LH=");
      Serial.println(current_value); 
      digitalWrite(3, LOW);
    }
    current_value = analogRead(1);//RH current reading
   
    //overcurrent? shut RH down
    if (current_value > (RH_zero_current + Current_limit))
    {
      Serial.print("Overcurrent RH=");
      Serial.println(current_value);
      digitalWrite(5, LOW);
    }
    if (current_value < (RH_zero_current - Current_limit))
    {
      Serial.print("Overcurrent RH=");
      Serial.println(current_value);
      digitalWrite(5, LOW);
    }
    if (count == 0) 
    {
      delay(50); //allow 50ms for inrush
    }
    else 
    {
      delay(10); //wait 10ms and check again
    }
    
    count++;
  } //end of while(count < 250)

  //done, turn off OPEN relays
  digitalWrite(3, LOW);//LH is off
  digitalWrite(5, LOW);//RH is off
}//end of Open_doors

void Check_toggles()
{
  //This routine runs a series of loops to trigger different mode toggles with the headlight switch.
  Toggle_count = 0;
  Second_toggle_count = 0;
  Sleepy_count = 0;
  Second_toggle = false;
  Do_wink_left = false;
  Do_wink_right = false;
  Mode_sleepy = false;
  
  while (Toggle_count < Toggle_loop_count) //gives time to give a switch toggle input rather than shutting down the module
  {
    if (digitalRead(7) == HIGH && digitalRead(8) == LOW) //Has the headlight switch been turned back on?
    {
      while (Second_toggle_count < Second_toggle_loop_count) //Loop to check for a second toggle input
      {
        if (digitalRead(7) == LOW && digitalRead(8) == HIGH) //Checks for a second toggle off
        {
          while (Sleepy_count < Sleepy_loop_count) //Checks for second toggle on. If left off, module will shutdown
          {
            if (digitalRead(7) == HIGH && digitalRead(8) == LOW) //Has the headlight switch been turned back on a second time?
            {
              Second_toggle = true; //a second toggle has happened
              if (Mode_normal == true)
              {
                Mode_sleepy = true; //sets sleepy mode
                Mode_normal = false;
                Sleepy_count = Sleepy_loop_count;
                Second_toggle_count = Second_toggle_loop_count;
                Toggle_count = Toggle_loop_count;
              }
              else
              {
                Mode_normal = true;
                Sleepy_count = Sleepy_loop_count;
                Second_toggle_count = Second_toggle_loop_count;
                Toggle_count = Toggle_loop_count;
              }
            }
            delay(10); //Wait 10ms and check again
            Sleepy_count++;
            
            if (Sleepy_count == 100)
            {
              Second_toggle_count = Second_toggle_loop_count;
            }
          } //End of Sleepy_count loop

        }
        
        delay(10);
        Second_toggle_count++;
      } //End of Second_toggle loop
      
      if (Second_toggle == false && digitalRead(7) == HIGH && digitalRead(8) == LOW)
      {
		if (Toggle_count >= 51)
		{
		  Do_wink_left = true;
		}
        
        if (Toggle_count < 51)
		{
		  Do_wink_right = true;
          Toggle_count = Toggle_loop_count;
		}
		
      }
    }
    delay(10);
    Toggle_count++;    
  } //End of Toggle_count loop
  
  //Checks the headlight switch one last time. If the switch is off, close doors and turn off module.
  //This ensures that Off does mean OFF. Also prevents the module getting lost if non-existent toggle command is given.
  if (digitalRead(7) == LOW && digitalRead(8) == HIGH)
  {
    Close_doors();
  }

  //Resolve mode selection
  
  if (Do_wink_left == true)
  {
    Do_wink_left = false;
	Wink_left();
	
  }
  
  if (Do_wink_right == true)
  {
	Do_wink_right = false;
    Wink_right();
  }
  
  if (Mode_sleepy == true)
  {
	Sleepy_mode();
  }
  
  if (Second_toggle == true && Mode_normal == true)
  {
    Open_doors();
  }
  

      
} //End of Check_toggles

void Wink_left()
{
  //no current should be present through the motor at this point so find the quiescent
  //value from the sensor
  LH_zero_current = analogRead(0); //this should be approximately 512 counts
  Serial.print("Zero Current LH=");
  Serial.println(LH_zero_current);
  
  count = 0;
  
  //Special close door timing for sleepy mode, this shouldn't need adjustment unless your motors are very slow.
  if (Mode_normal == false)
  {
    count = 85;
  }
  
  //Make sure OPEN signal is OFF
  digitalWrite(3, LOW); //open is off for LH

  //now turn ON CLOSE signal
  digitalWrite(4, HIGH);//LH is on
  
   while (count < Loop_count) //wait for doors to complete operation or overcurrent happens
  {
    current_value = analogRead(0);//LH current reading
    
    //overcurrent? shut LH down
    if (current_value > (LH_zero_current + Current_limit))
    {
      Serial.print("Overcurrent LH=");
      Serial.println(current_value);
      digitalWrite(4, LOW);
    }
    if (current_value < (LH_zero_current - Current_limit))
    {
      Serial.print("Overcurrent LH=");
      Serial.println(current_value);
      digitalWrite(4, LOW);
    }
    
  if (count == 0) 
    {
      delay(50); //allow 50ms for inrush
    }
    else 
    {
      delay(10); //wait 10ms and check again
    }
       count++;
  } //end of while(count < 250)

  //done, turn off CLOSE relay
  digitalWrite(4, LOW);//LH is off
  
  delay(30);//short delay before switching to open
  count = 0;//reset count for open loop
  
  //Special open door timing for sleepy mode winks.
  //If count is set higher, the motor will run shorter and open less.
  //If set lower, the motor will run longer and open more.
  //Adjust this for your own car if the default setting isn't raising the light to the desired height.
  if (Mode_normal == false)
  {
    count = 70;
  }
  
  //Re-open the left door
  //now turn ON OPEN signals
  digitalWrite(3, HIGH);//LH is on
  
  while (count < Loop_count) //wait for door to complete operation or overcurrent happens
  {
    current_value = analogRead(0);//LH current reading
    //overcurrent? shut LH down
    if (current_value > (LH_zero_current + Current_limit)) 
    {
      Serial.print("Overcurrent LH=");
      Serial.println(current_value);  
      digitalWrite(3, LOW);
    }
    if (current_value < (LH_zero_current - Current_limit))
    {
      Serial.print("Overcurrent LH=");
      Serial.println(current_value); 
      digitalWrite(3, LOW);
    }
   
    if (count == 0) 
    {
      delay(50); //allow 50ms for inrush
    }
    else 
    {
      delay(10); //wait 10ms and check again
    }
    
    count++;
  } //end of while(count < 250)

  //done, turn off OPEN relays
  digitalWrite(3, LOW);//LH is off
}//end of Wink_left


void Wink_right()
{
  //no current should be present through the motor at this point so find the quiescent
  //value from the sensor
  RH_zero_current = analogRead(1); //this should be approximately 512 counts
  Serial.print("Zero Current RH=");
  Serial.println(RH_zero_current);
  
  count = 0;
  
  //Special close door timing for sleepy mode, this shouldn't need adjustment unless your motors are very slow.
  if (Mode_normal == false)
  {
    count = 85;
  }
  
  //Make sure OPEN signal is OFF
  digitalWrite(5, LOW); //open is off for RH

  //now turn ON CLOSE signal
  digitalWrite(6, HIGH);//RH is on
  
   while (count < Loop_count) //wait for door to complete operation or overcurrent happens
  {
    current_value = analogRead(1);//RH current reading
    
    //overcurrent? shut RH down
    if (current_value > (RH_zero_current + Current_limit))
    {
      Serial.print("Overcurrent RH=");
      Serial.println(current_value);
      digitalWrite(6, LOW);
    }
    if (current_value < (RH_zero_current - Current_limit))
    {
      Serial.print("Overcurrent RH=");
      Serial.println(current_value);
      digitalWrite(6, LOW);
    }
    
  if (count == 0) 
    {
      delay(50); //allow 50ms for inrush
    }
    else 
    {
      delay(10); //wait 10ms and check again
    }
       count++;
  } //end of while(count < 250)

  //done, turn off CLOSE relay
  digitalWrite(6, LOW);//RH is off
  
  delay(30);//short delay before switching to open
  
  //Special open door timing for sleepy mode winks.
  //If count is set higher, the motor will run shorter and open less.
  //If set lower, the motor will run longer and open more.
  //Adjust this for your own car if the default setting isn't raising the light to the desired height.
  count = 0;//reset count for open loop
  if (Mode_normal == false)
  {
    count = 70;
  }
  
  //Re-open the left door
  //now turn ON OPEN signals
  digitalWrite(5, HIGH);//RH is on
  
  while (count < Loop_count) //wait for door to complete operation or overcurrent happens
  {
    current_value = analogRead(1);//RH current reading
    //overcurrent? shut RH down
    if (current_value > (RH_zero_current + Current_limit)) 
    {
      Serial.print("Overcurrent RH=");
      Serial.println(current_value);  
      digitalWrite(5, LOW);
    }
    if (current_value < (RH_zero_current - Current_limit))
    {
      Serial.print("Overcurrent RH=");
      Serial.println(current_value); 
      digitalWrite(5, LOW);
    }
   
    if (count == 0) 
    {
      delay(50); //allow 50ms for inrush
    }
    else 
    {
      delay(10); //wait 10ms and check again
    }
    
    count++;
  } //end of while(count < 250)

  //done, turn off OPEN relay
  digitalWrite(5, LOW);//LH is off
}//end of Wink_right

void Sleepy_mode()
{
  //This routine runs the close relays for roughly 1 second to partially close the headlights, giving the car a sleepy look.
  //It performs the same functions as the Close_doors routine, but starts the count at a higher number, reducing runtime.
  //it also doesn't turn off the module at the end.
  
  //no current should be present through the motors at this point so find the quiescent
  //value from the sensors
  LH_zero_current = analogRead(0); //this should be approximately 512 counts
  RH_zero_current = analogRead(1); //this should be approximately 512 counts
  Serial.print("Zero Current LH=");
  Serial.println(LH_zero_current);
  Serial.print("Zero Current RH=");
  Serial.println(RH_zero_current); 
  
  count = 105;//Start count high to reduce runtime
  //Make sure OPEN signals are OFF
  digitalWrite(3, LOW); //open is off for LH
  digitalWrite(5, LOW); //open is off for RH
  //now turn ON CLOSE signals
  digitalWrite(4, HIGH);//LH is on
  digitalWrite(6, HIGH);//RH is on

  while (count < Loop_count) //wait for doors to complete operation or overcurrent happens
  {
    current_value = analogRead(0);//LH current reading
    
    //overcurrent? shut LH down
    if (current_value > (LH_zero_current + Current_limit))
    {
      Serial.print("Overcurrent LH=");
      Serial.println(current_value);
      digitalWrite(4, LOW);
    }
    if (current_value < (LH_zero_current - Current_limit))
    {
      Serial.print("Overcurrent LH=");
      Serial.println(current_value);
      digitalWrite(4, LOW);
    }
    current_value = analogRead(1);//RH current reading
    
    //overcurrent? shut RH down
    if (current_value > (RH_zero_current + Current_limit))
    {
      Serial.print("Overcurrent RH=");
      Serial.println(current_value);
      digitalWrite(6, LOW);
    }
    if (current_value < (RH_zero_current - Current_limit))
    {
      Serial.print("Overcurrent RH=");
      Serial.println(current_value);
      digitalWrite(6, LOW);
    }
    if (count == 150) 
    {
      delay(50); //allow 50ms for inrush
    }
    else 
    {
      delay(10); //wait 10ms and check again
    }
       count++;
  } //end of while(count < 250)

  //done, turn off CLOSE relays
  digitalWrite(4, LOW);//LH is off
  digitalWrite(6, LOW);//RH is off
}//End of Sleepy_mode
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

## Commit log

2024-05-09 Add project and gerber files
    [Headlight Controller 1_1-B_Cu.gbr, Headlight Controller 1_1-B_Mask.gbr, Headlight Controller 1_1-B_Paste.gbr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]
2024-05-09 Add Arduino Program
2024-05-10 Added pin headers for current sensors
2024-05-11 Update BOM.md
    Forgot to add capacitors previously
2024-05-11 Re-zipped Gerber Files
    Replaced the pre-zipped gerber files as the previous zip archive occasionally gave an error when uploading to JLCPCB.
2025-06-14 Add files for v1.2 - added socketed fuse holders
    [Headlight Controller 1_2-B_Cu.gbr, Headlight Controller 1_2-B_Mask.gbr, Headlight Controller 1_2-B_Paste.gbr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]
